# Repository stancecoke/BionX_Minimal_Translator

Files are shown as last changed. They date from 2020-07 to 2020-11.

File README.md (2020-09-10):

# BionX_Minimal_Translator

Run a BionX Motor with a Kunteng LCD-Display  



[Discussion in german forum](https://www.pedelecforum.de/forum/index.php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)  
["Bluepill" STM32F103 Board](https://rover.ebay.com/rover/1/707-53477-19255-0/1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)  
[CAN-Driver-Board](https://rover.ebay.com/rover/1/707-53477-19255-0/1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)  
[Step Down Converter 12V + 5V](https://rover.ebay.com/rover/1/707-53477-19255-0/1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)  
[Kunteng Display](https://rover.ebay.com/rover/1/707-53477-19255-0/1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)

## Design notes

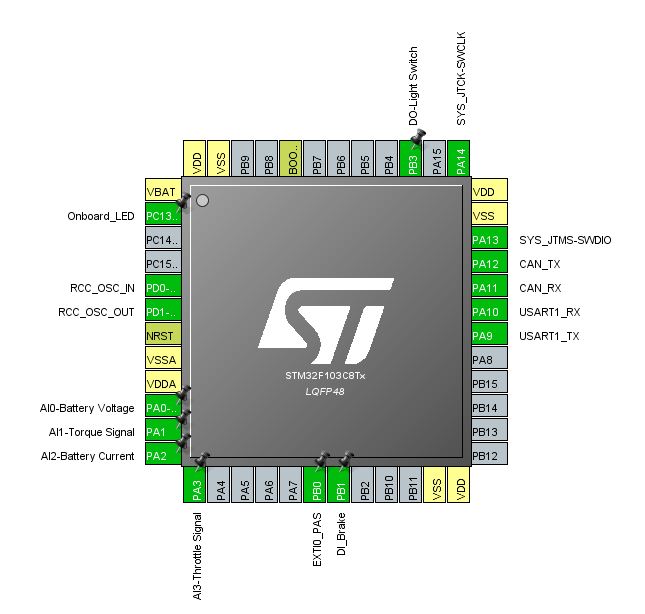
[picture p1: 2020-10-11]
KiCAD/Processor Pinout.JPG

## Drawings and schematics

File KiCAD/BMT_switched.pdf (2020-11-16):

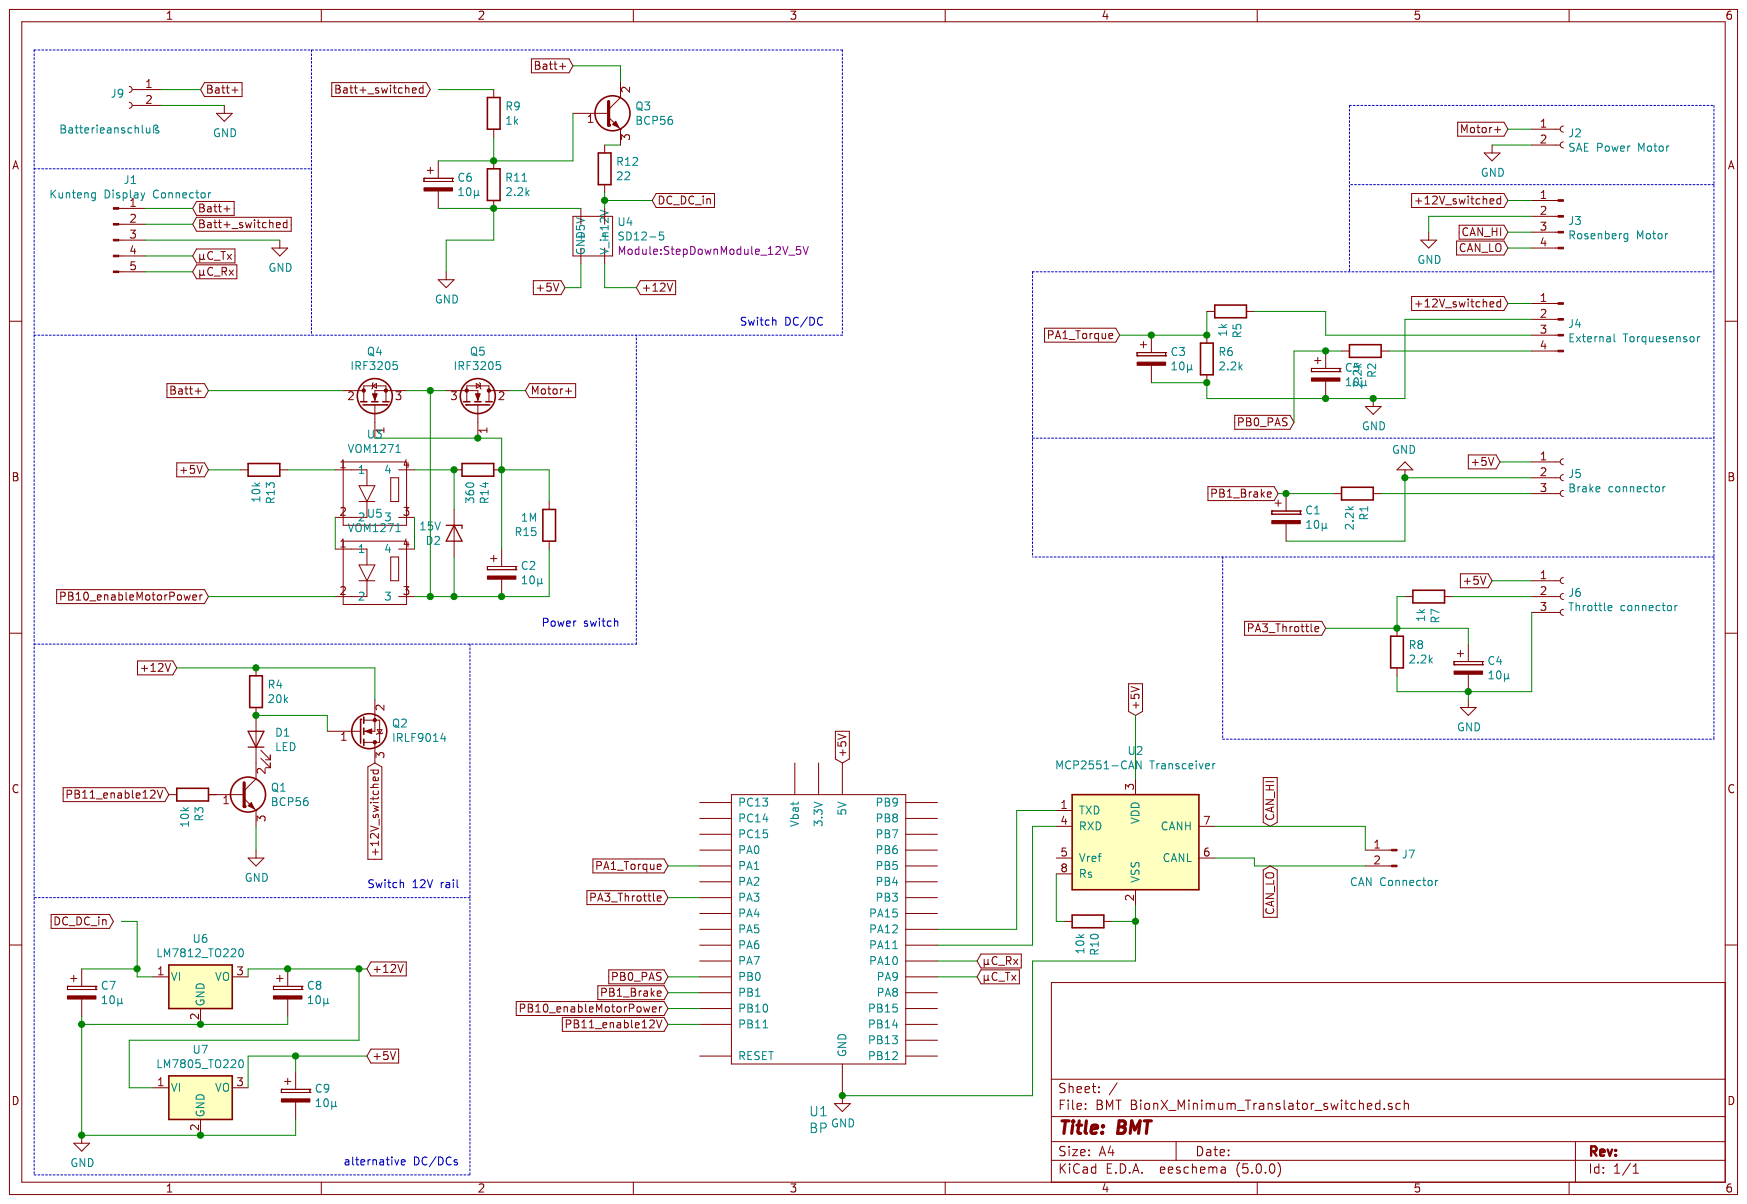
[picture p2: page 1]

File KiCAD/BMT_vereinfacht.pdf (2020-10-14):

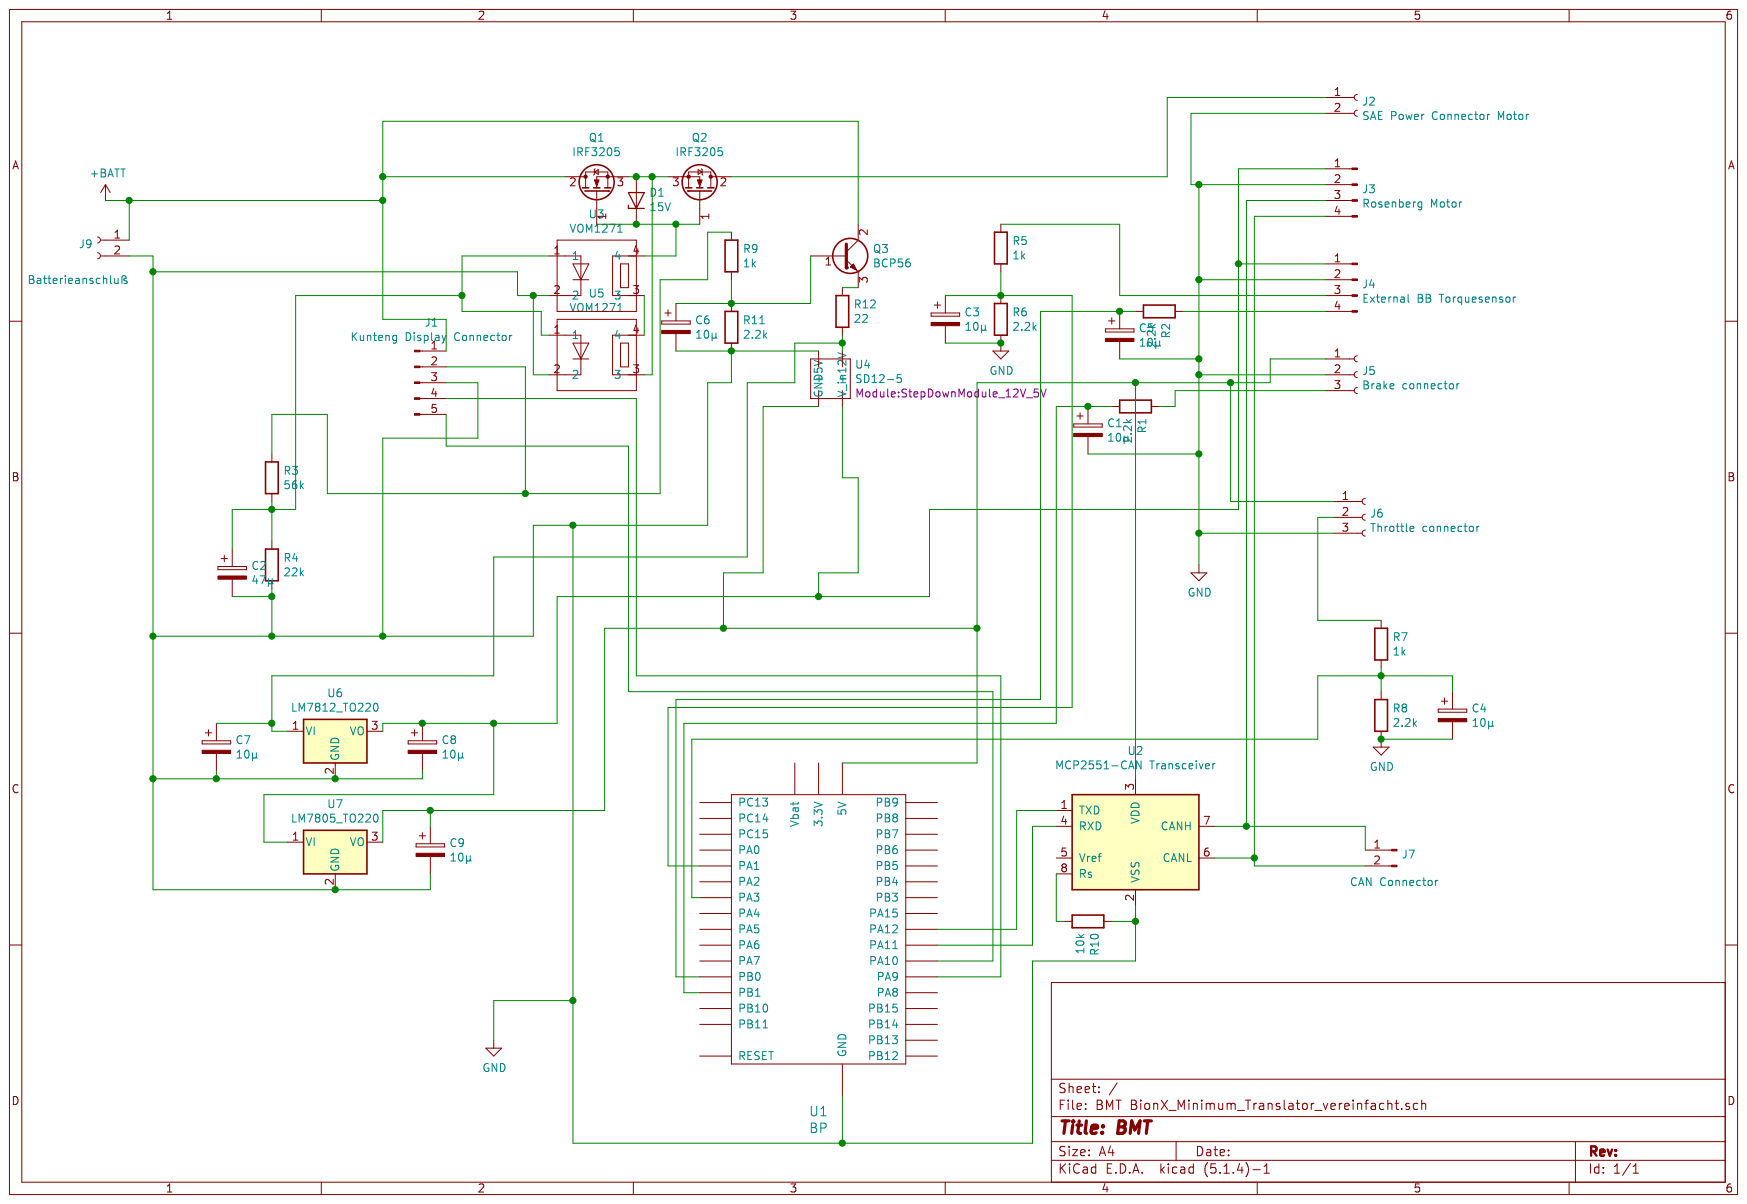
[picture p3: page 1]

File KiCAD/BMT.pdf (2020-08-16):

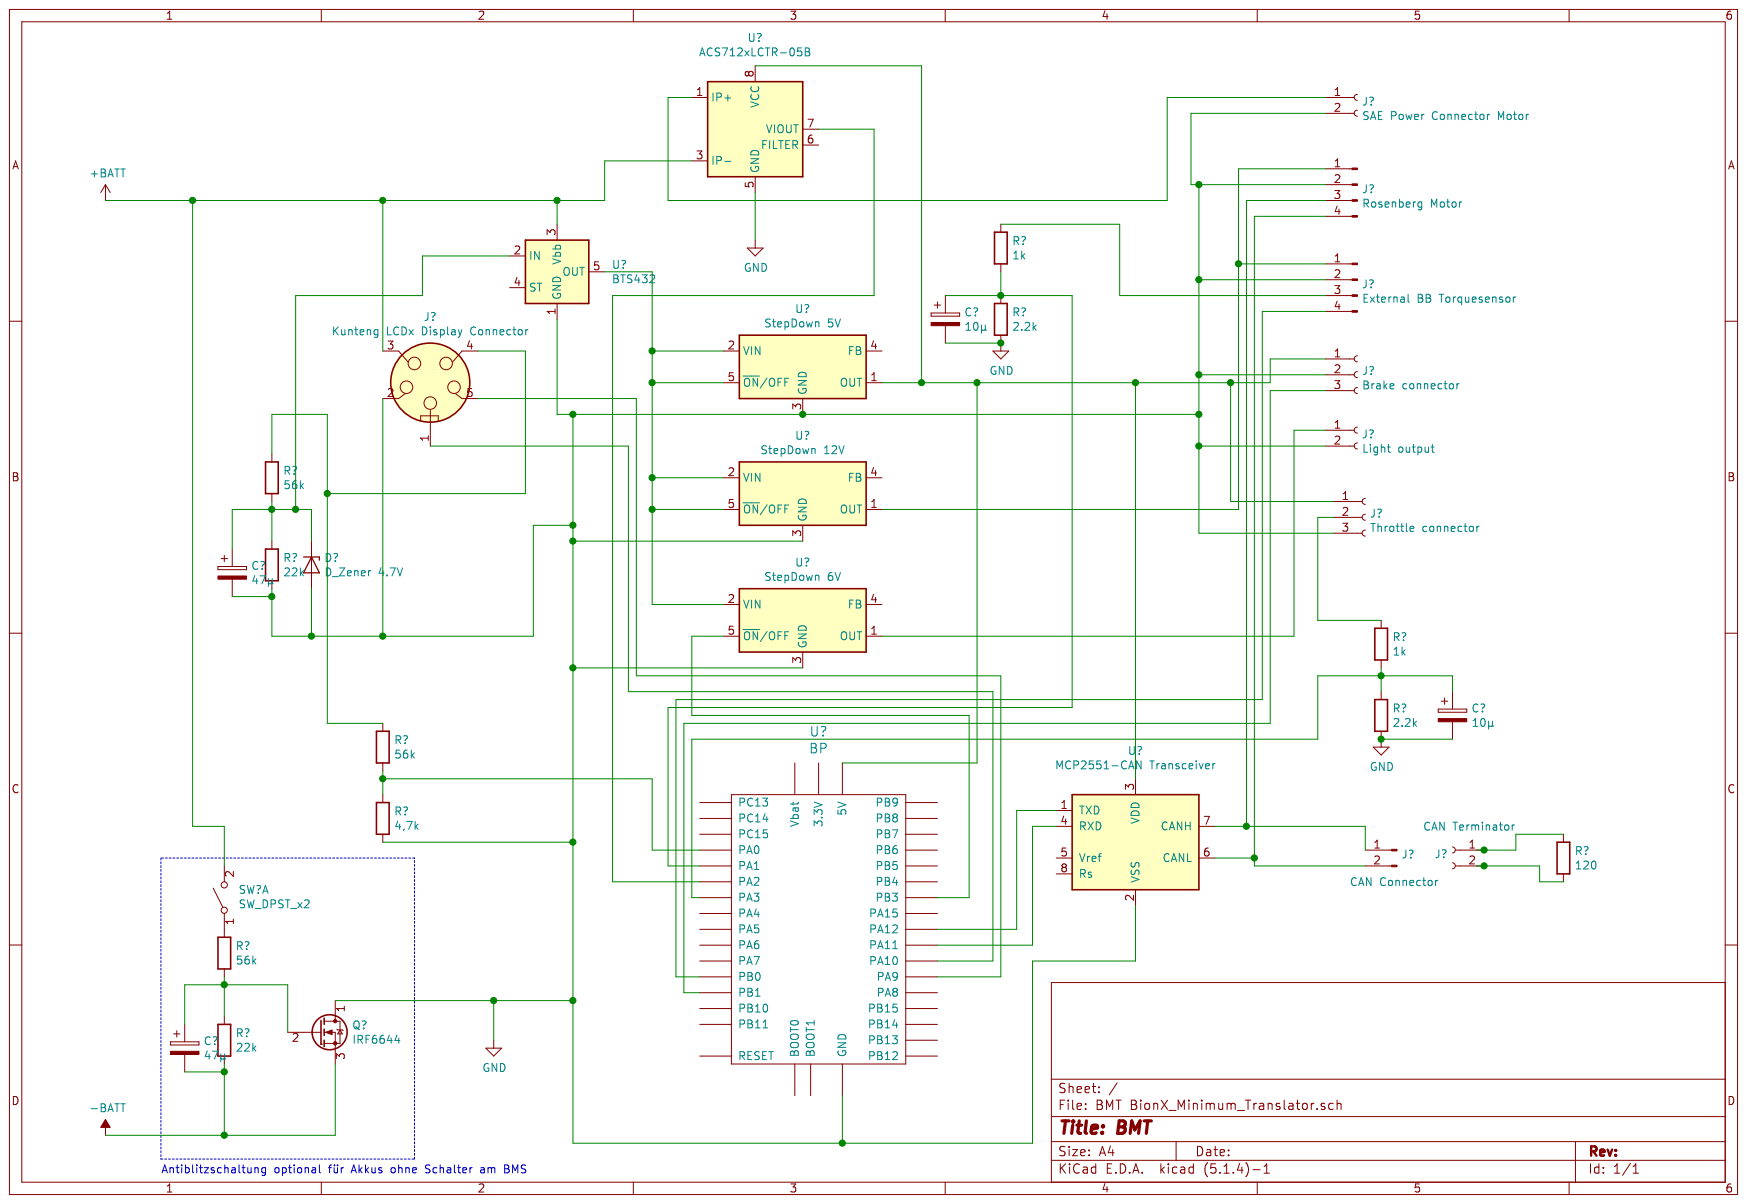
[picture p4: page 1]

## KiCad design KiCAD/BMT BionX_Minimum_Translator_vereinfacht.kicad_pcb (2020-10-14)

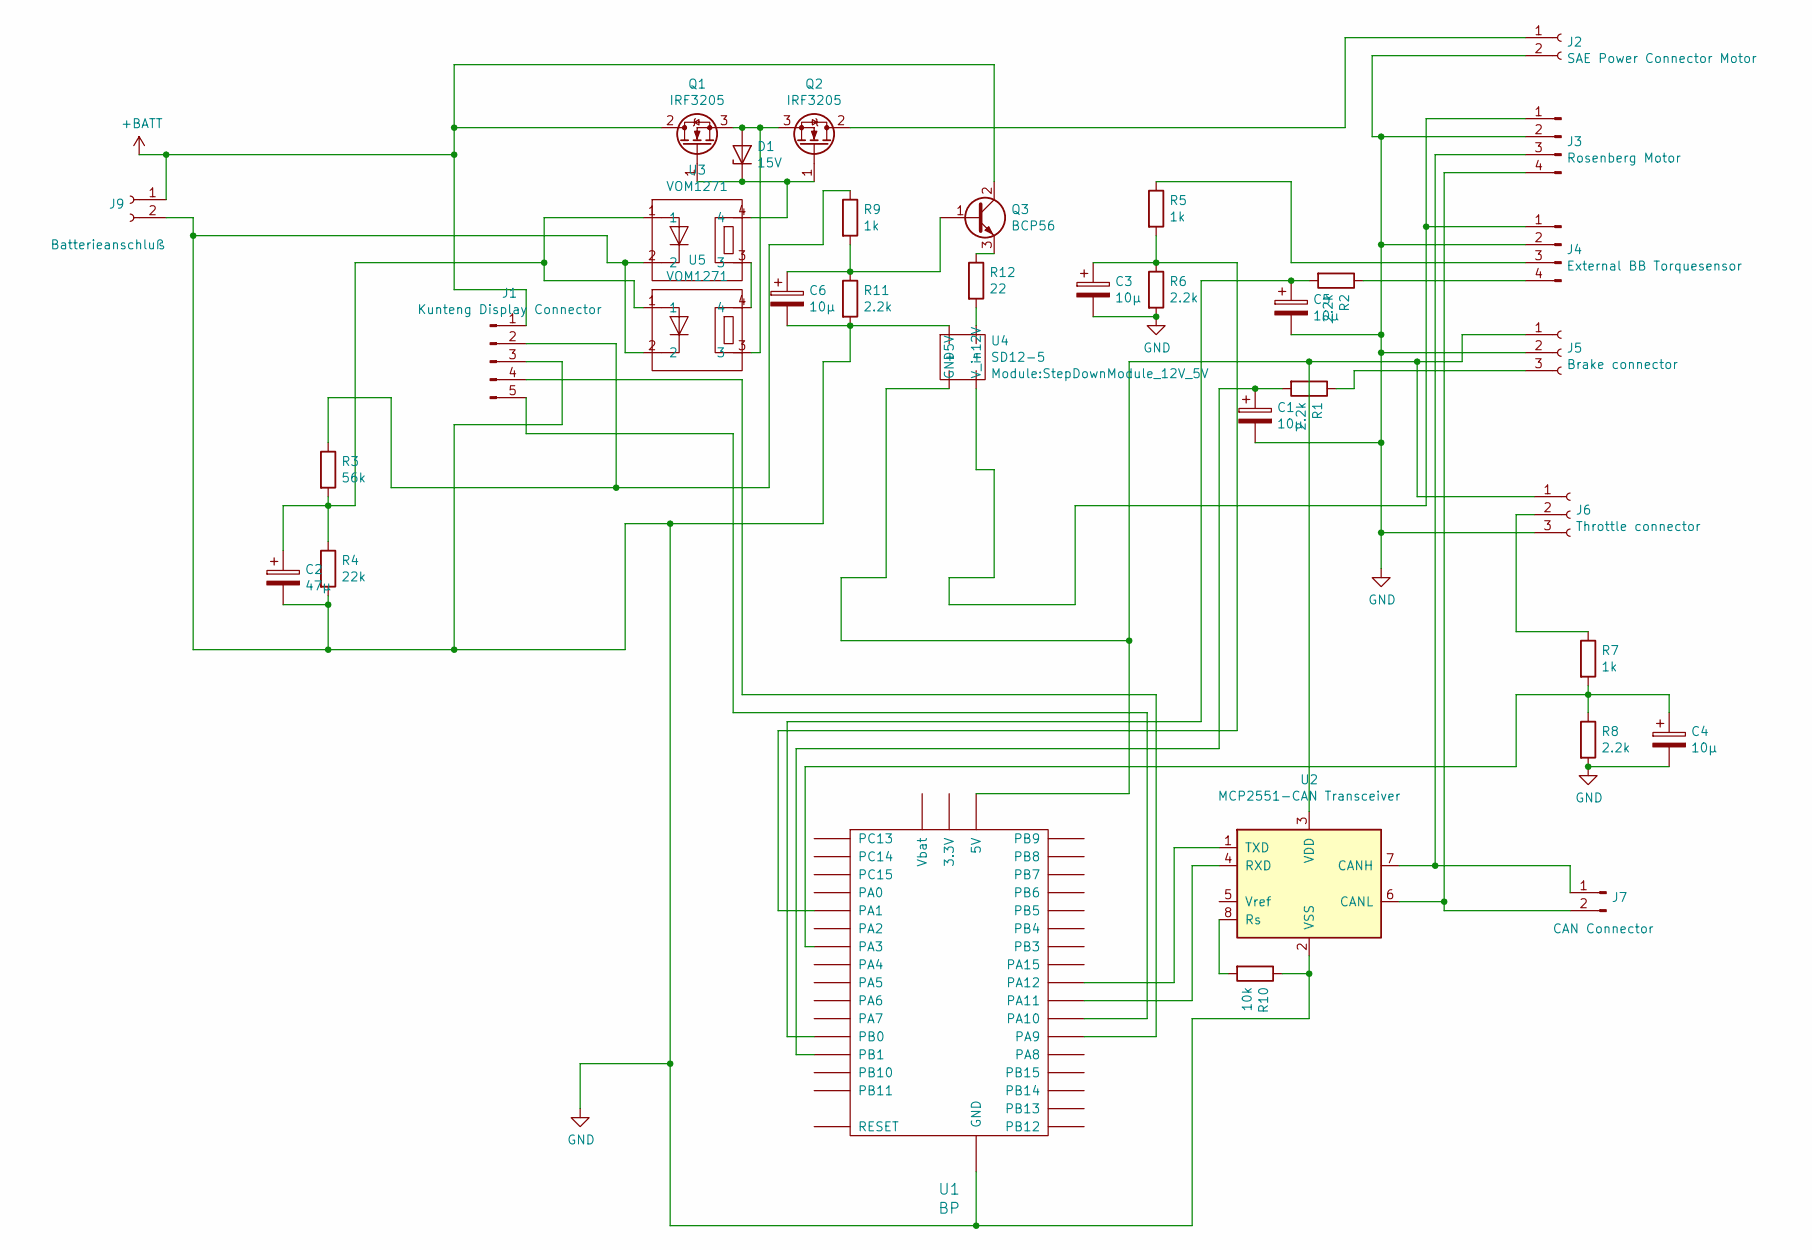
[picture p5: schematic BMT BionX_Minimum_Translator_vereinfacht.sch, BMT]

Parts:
C1, C3, C4, C5, C6: 10µ; CP_Radial_D5.0mm_P2.50mm
C2: 47µ; CP_Radial_D5.0mm_P2.50mm
D1: 15V; D_0805_2012Metric
J1: Kunteng Display Connector; JST_EH_B5B-EH-A_1x05_P2.50mm_Vertical
J2: SAE Power Connector Motor; Wago_734-132_1x02_P3.50mm_Vertical
J3: Rosenberg Motor; JST_EH_B4B-EH-A_1x04_P2.50mm_Vertical
J4: External BB Torquesensor; JST_EH_B4B-EH-A_1x04_P2.50mm_Vertical
J5: Brake connector; JST_EH_B3B-EH-A_1x03_P2.50mm_Vertical
J6: Throttle connector; JST_EH_B3B-EH-A_1x03_P2.50mm_Vertical
J7: CAN Connector; JST_EH_B2B-EH-A_1x02_P2.50mm_Vertical
J9: Batterieanschluß; Wago_734-132_1x02_P3.50mm_Vertical
Q1, Q2: IRF3205; TO-220-3_Vertical
Q3: BCP56; SOT-223
R1, R2, R6, R8, R11: 2.2k; R_0805_2012Metric
R3: 56k; R_0805_2012Metric
R4: 22k; R_0805_2012Metric
R5, R7, R9: 1k; R_0805_2012Metric
R10: 10k; R_0805_2012Metric
R12: 22; R_0805_2012Metric
U1: BP; BluePill
U2: MCP2551-CAN Transceiver; SOIC-8-1EP_3.9x4.9mm_P1.27mm_EP2.29x3mm
U3, U5: VOM1271; SOP-4_3.8x4.1mm_P2.54mm
U4: SD12-5; StepDownModule_12V_5V

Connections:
+BATT: J1.1, J9.1, Q1.2 (D), Q3.2 (C), Q3.4 (C)
GND: C1.2, C2.2, C3.2, C4.2, C5.2, C6.2, J1.3, J2.2, J3.2, J4.2, J5.2, J6.3, J9.2, R4.2, R6.2, R8.2, R10.1, R11.2, U1.GND, U2.2 (VSS), U3.2, U4.GND, U5.2; also elsewhere on the board
unnamed: C1.1, R1.2, U1.PB1
unnamed: C2.1, R3.2, R4.1, U3.1, U5.1
unnamed: C3.1, R5.2, R6.1, U1.PA1
unnamed: C4.1, R7.2, R8.1, U1.PA3
unnamed: C5.1, R2.2, U1.PB0
unnamed: C6.1, Q3.1 (B), R9.2, R11.1
unnamed 8: R12.2, U4.V_in; also elsewhere on the board
unnamed 9: J3.1, J4.1, U4.+12V; also elsewhere on the board
unnamed 10: J5.1, J6.1, U1.5V, U2.3 (VDD), U4.+5V; also elsewhere on the board
unnamed: D1.1 (K), Q1.1 (G), Q2.1 (G), U3.4
unnamed: D1.2 (A), Q1.3 (S), Q2.3 (S), U5.3
unnamed: J1.2, R3.1, R9.1
unnamed: J1.4, U1.PA9
unnamed: J1.5, U1.PA10
unnamed: J2.1, Q2.2 (D)
unnamed: J3.3, J7.1, U2.7 (CANH)
unnamed: J3.4, J7.2, U2.6 (CANL)
unnamed: J4.3, R5.1
unnamed: J4.4, R2.1
unnamed: J5.3, R1.1
unnamed: J6.2, R7.1
unnamed: Q3.3 (E), R12.1
unnamed: R10.2, U2.8 (Rs)
unnamed: U1.PA11, U2.4 (RXD)
unnamed: U1.PA12, U2.1 (TXD)
unnamed: U3.3, U5.4

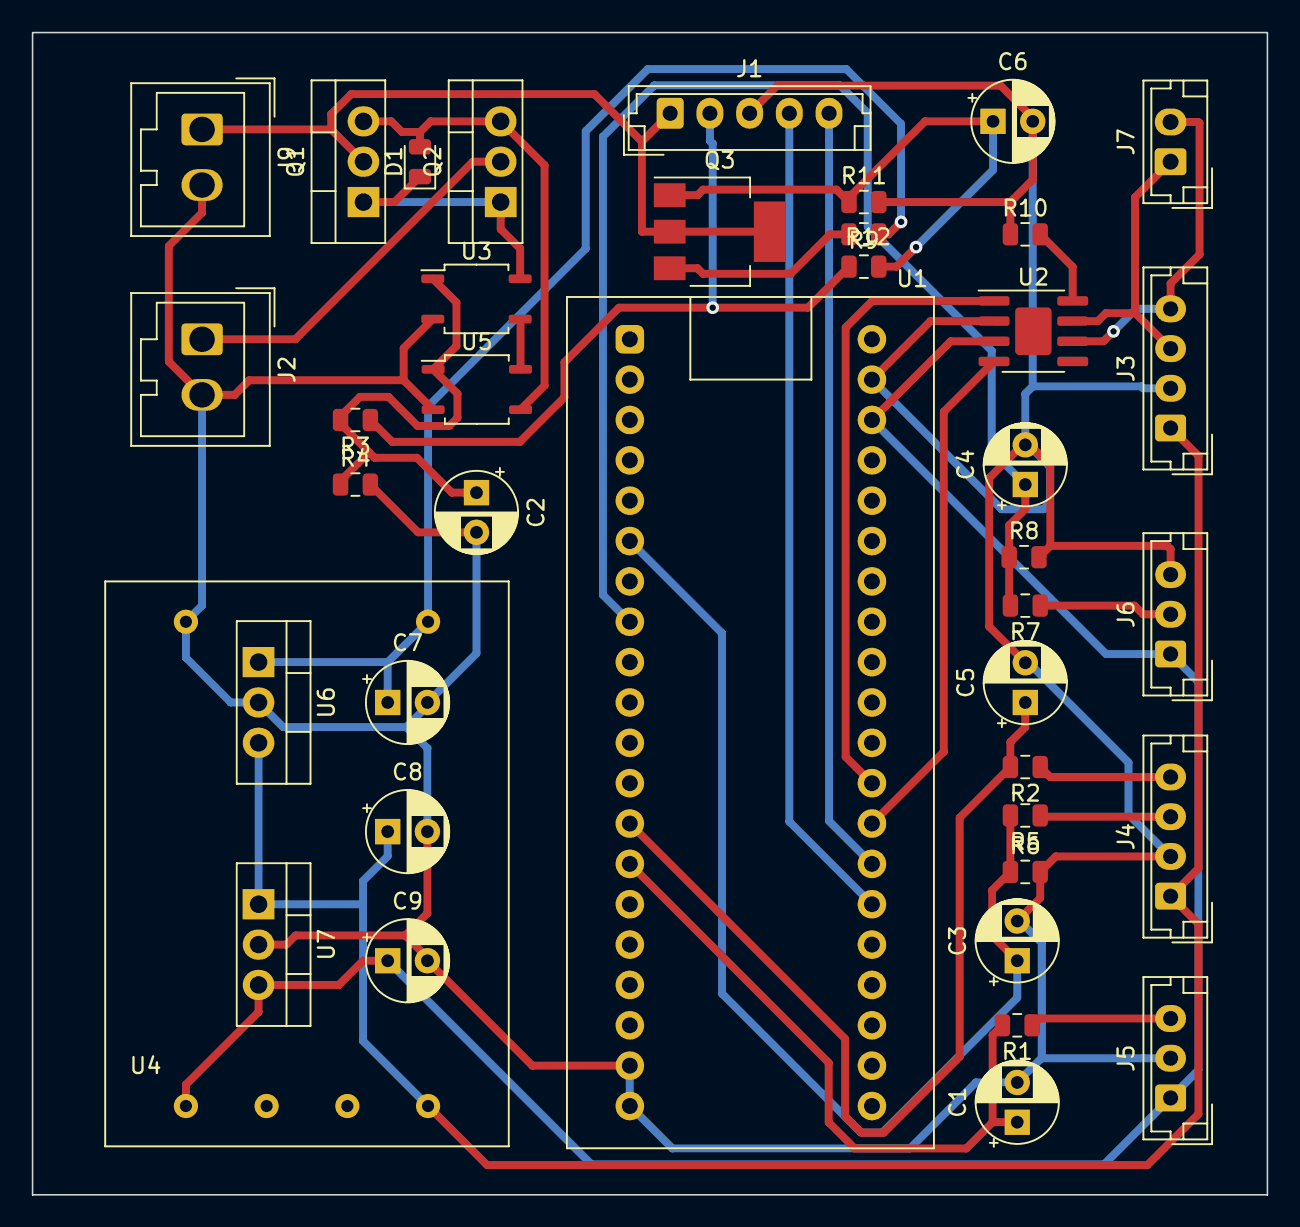
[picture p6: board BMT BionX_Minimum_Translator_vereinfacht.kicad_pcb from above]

Board: 2 copper layers, 77.7 x 73.2 mm, 40 parts (0 on the bottom side), 28 nets.

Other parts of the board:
C7, C8, C9: 10µ; CP_Radial_D5.0mm_P2.50mm
U6: LM7812_TO220; TO-220-3_Vertical
U7: LM7805_TO220; TO-220-3_Vertical

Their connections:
GND: C7.2, C8.2, C9.2, U6.2, U7.2; also elsewhere on the board
unnamed 8: C7.1, U6.1; also elsewhere on the board
unnamed 9: C8.1, U6.3, U7.1; also elsewhere on the board
unnamed 10: C9.1, U7.3; also elsewhere on the board

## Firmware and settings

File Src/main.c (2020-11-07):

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

/* Includes ------------------------------------------------------------------*/
#include "main.h"

/* USER CODE BEGIN Includes */
#include <stdio.h>
#include "config.h"
#include "display_kunteng.h"
#include "CAN-Registers.h"
/* USER CODE END Includes */

ADC_HandleTypeDef hadc1;
DMA_HandleTypeDef hdma_adc1;

CAN_HandleTypeDef hcan;

TIM_HandleTypeDef htim3;

UART_HandleTypeDef huart1;
DMA_HandleTypeDef hdma_usart1_rx;
DMA_HandleTypeDef hdma_usart1_tx;

/* USER CODE BEGIN PV */
char UART_TX_Buffer[100];
char UART_RX_Buffer[100];
uint8_t i=0; //counter for loops
uint8_t j=0; //counter for autozero at startup
uint8_t k=0; //counter for fast CAN_TX
uint8_t l=0; //counter for slow CAN_TX
uint8_t UART_RX_Flag=0;
uint8_t Brake_Flag_Old=0;
uint8_t UART_TX_Flag=1;
uint8_t CAN_RX_Flag=0;
uint8_t CAN_TX_Flag=0;
uint8_t Timer3_Flag=0;
uint8_t ADC_Flag=0;
uint8_t PAS_Flag=0;
char ch_GaugeVoltage_Lo=0;
char ch_GaugeVoltage_Hi=0;
char ch_BatteryVoltage_Lo=0;
char ch_BatteryVoltage_Hi=0;

int8_t i8_Throttle=0; //must be scaled to valid values from -64 ... +64
int16_t i16_Gauge_Torque=0;
int16_t i16_Gauge_Timeout_counter=0;
int16_t i16_Gauge_Voltage=0;
uint16_t ui16_Ext_Torque=0;
uint32_t ui32_Ext_Torque_Cumulated=0;
int16_t i16_PAS_Counter=0;
int16_t i16_PAS_Duration=PAS_TIMEOUT;
int32_t i32_Gauge_Torque_cumulated=0;
int32_t i32_Speed_cumulated=0;
int16_t i16_Current_Target=0;
uint16_t ui16_slow_loop_counter=0;
uint16_t ui16_Gauge_Gain;
volatile uint16_t adcData[4]; //Buffer for ADC1 Input
MotorState_t MS; //struct for motor state


CAN_TxHeaderTypeDef   TxHeader;
CAN_RxHeaderTypeDef   RxHeader;
uint8_t               TxData[8];
uint8_t               RxData[8];
uint32_t              TxMailbox;
/* USER CODE END PV */

void SystemClock_Config(void);
static void MX_GPIO_Init(void);
static void MX_DMA_Init(void);
static void MX_CAN_Init(void);
static void MX_USART1_UART_Init(void);
static void MX_ADC1_Init(void);
static void MX_TIM3_Init(void);


int32_t map (int32_t x, int32_t in_min, int32_t in_max, int32_t out_min, int32_t out_max);
int16_t PI_control (int16_t ist, int16_t soll, int16_t max);
/**
  * @brief  The application entry point.
  * @retval int
  */
int main(void)
{
  /* MCU Configuration--------------------------------------------------------*/

  /* Reset of all peripherals, Initializes the Flash interface and the Systick. */
  HAL_Init();

  /* Configure the system clock */
  SystemClock_Config();

  /* Initialize all configured peripherals */
  MX_GPIO_Init();
  MX_DMA_Init();
  MX_CAN_Init();
  MX_USART1_UART_Init();
  MX_ADC1_Init();
#if (DISPLAY_TYPE == DISPLAY_TYPE_KUNTENG)
  kunteng_init();
#endif
  /* Run the ADC CALIB_GAUGEration */


  {
    /* CALIB_GAUGEration Error */
    Error_Handler();
  }

  MX_TIM3_Init();

  // Start Timer 3

  if(HAL_TIM_Base_Start_IT(&htim3) != HAL_OK)
       {
         /* Counter Enable Error */
         Error_Handler();
       }
  // Start ADC1 with DMA
  HAL_ADC_Start_DMA(&hadc1, (uint32_t*)adcData, 4);

  /* USER CODE BEGIN 2 */

  UART_RX_Buffer[0]=0;


  while(!CAN_RX_Flag){ //So lange Versionsanfrage senden, bis Antwort vom BionX-Controller kommt, dabei blinken.
  	  HAL_Delay(200);
  	  HAL_GPIO_TogglePin(Onboard_LED_GPIO_Port, Onboard_LED_Pin);
		Send_CAN_Request(REG_MOTOR_REV_SW);

		  }
  HAL_Delay(200);

  MS.Gauge_Ext_Torq_Flag = 1; 	//set torque source to external BB-sensor by default. Is overwritten by KT-LCD setting of P3 at runtime.
  MS.Assist_Level = 3;			//set Assistlevel to 3 as default value
  MS.Gauge_Factor = 127;		//default for global gain for torque measurement, set by Kunteng Paramter P1 0 ... 255
  MS.Regen_Factor = 4;			//default regen strenght for brake lever regen
  MS.Throttle_Function = 0; 	//Throttle override for power and regen
  MS.Min_Voltage = 33000;		//minimum Voltage (mV) for 10s pack as default
  MS.Max_Voltage = 41500;		//maximum Voltage (mV) for 10s pack as default
  MS.Filter = 6;				//Filter over 64 readings as default.

  /* USER CODE END 2 */

  /* Infinite loop */
  /* USER CODE BEGIN WHILE */
  while (1)
  {



	  if(UART_RX_Flag){
		  UART_RX_Flag=0;

#if (DISPLAY_TYPE == DISPLAY_TYPE_DEBUG)
		  if(UART_TX_Flag){
			 UART_TX_Flag=0;


		  	sprintf(UART_TX_Buffer, "Empfangenes UART Byte %d, %d, %d, %d\r\n",UART_RX_Buffer[0],UART_RX_Buffer[1], UART_RX_Buffer[2], UART_RX_Buffer[3]);

		  	  	  i=0;
		  	  	  while (UART_TX_Buffer[i] != '\0')
		  	  	  {i++;}


		  	  	HAL_UART_Transmit_DMA(&huart1, (uint8_t *)&UART_TX_Buffer, i);

		  }

		  	  if(CAN_TX_Flag && UART_RX_Buffer[0]==1){
		  		CAN_TX_Flag=0;
		  		Send_CAN_Command(UART_RX_Buffer[1],((uint16_t)UART_RX_Buffer[2]<<8)+UART_RX_Buffer[3]); //send command with UART-Input
		  	  }


#endif
#if (DISPLAY_TYPE == DISPLAY_TYPE_KUNTENG)
		  	check_message(&MS);

#endif
	  } //end uart rx flag

	  //Timer 3 running with 1kHz ISR frequency
	  if(Timer3_Flag){

		  Timer3_Flag=0;
		  ui16_slow_loop_counter++;
		  if (i16_PAS_Counter<PAS_TIMEOUT)i16_PAS_Counter++;

		  MS.Voltage=ch_BatteryVoltage_Hi<<8|ch_BatteryVoltage_Hi; //Battery Voltage in mV
		  i16_Gauge_Voltage=ch_GaugeVoltage_Hi<<8|ch_GaugeVoltage_Lo;

		  //Bremseingang abfragen
		  MS.Brake=HAL_GPIO_ReadPin(Brake_GPIO_Port, Brake_Pin);
		  // hier ggf. noch entprellen?
		  if(MS.Brake==0 && Brake_Flag_Old==1){
			  PI_control (MS.Voltage, MS.Max_Voltage, 0); //reset integral part of PI control, if brake lever is released
			  if(MS.Assist_Level==0){ //Toggle
				  if(MS.Perma_Regen)MS.Perma_Regen=0;
				  else MS.Perma_Regen=1;
			  }
		  }
		  Brake_Flag_Old=MS.Brake;
		  //read in throttle signal
		  i8_Throttle=map(adcData[3],THROTTLE_MIN,THROTTLE_MAX, 0, 63); //map throttle ADC-value to valid LEVEL range

		  //process PAS signal
		  if (PAS_Flag){
			  HAL_GPIO_TogglePin(Onboard_LED_GPIO_Port, Onboard_LED_Pin);
			  PAS_Flag=0;
			  i16_PAS_Duration=i16_PAS_Counter;
			  i16_PAS_Counter=0;
			  ui16_Ext_Torque=map(adcData[1],EXT_TORQUE_MIN, EXT_TORQUE_MAX, 0, 1024); //map throttle ADC-value to valid LEVEL range
			  ui32_Ext_Torque_Cumulated-=ui32_Ext_Torque_Cumulated>>MS.Filter;
			  ui32_Ext_Torque_Cumulated+=ui16_Ext_Torque;

		  }

		  if (ui16_slow_loop_counter>5){

			  ui16_slow_loop_counter=0;

			  //Brake acitve, do constant regen
			  if(!MS.Brake){
				  i16_Current_Target = (-CALIB_REGEN*(MS.Regen_Factor+1))>>3;		//regen via brake lever
				  if(!MS.Throttle_Function)i8_Throttle=-i8_Throttle;
			  }
			  //Perma Regen active, do regen according to assist level
			  else if(MS.Perma_Regen){
				  i16_Current_Target = (-CALIB_REGEN*MS.Assist_Level)/5;		//permanent regen switched by tip on brake lever in level 0
				  if(!MS.Throttle_Function)i8_Throttle=-i8_Throttle;
			  }
			  // if internal Gauge is active (selected by P3), calculate current target from Gauge Value,
			  else if(MS.Gauge_Ext_Torq_Flag){
				  i16_Current_Target = (CALIB_GAUGE*(i32_Gauge_Torque_cumulated>>MS.Filter)*MS.Assist_Level*MS.Gauge_Factor)>>7; //normal ride mode
			  	  if(!i16_Gauge_Torque)i16_Gauge_Timeout_counter++;  	//count up readings with gauge value == 0
			  	  else i16_Gauge_Timeout_counter = 0;					//reset timeout counter, when gauge value != 0
			  	  if (i16_Gauge_Timeout_counter>PAS_TIMEOUT-1){			//if gauge value has timed out, slowly decrease Torque_cumulated.
			  		  i16_Gauge_Timeout_counter=PAS_TIMEOUT;
			  		  if(i32_Gauge_Torque_cumulated>0)i32_Gauge_Torque_cumulated--;
			  	  }
			  }
			  // if external torque sensor is active
			  else {
				  i16_Current_Target = (((ui32_Ext_Torque_Cumulated>>MS.Filter)*MS.Assist_Level*MS.Gauge_Factor)>>CALIB_EXT_TORQUE)/(i16_PAS_Duration*(MS.Speed+1));
				  if(i16_PAS_Counter>PAS_TIMEOUT-1){
					  i16_Current_Target=0; //Switch off power, if pedals are not turning
					  if(ui32_Ext_Torque_Cumulated>0)ui32_Ext_Torque_Cumulated--;
					  if(i16_PAS_Duration<PAS_TIMEOUT)i16_PAS_Duration++;

				  }
			  }

			  // limit Current_Target to valid range for LEVEL
			  if(i16_Current_Target>63)i16_Current_Target=63;
			  if(i16_Current_Target<-63)i16_Current_Target=-63;

			  if(!MS.Throttle_Function){
				  // Throttle override for regen and assist

				  if(MS.Gauge_Ext_Torq_Flag){
					  if(i16_Current_Target>=0 && i8_Throttle>0 && i8_Throttle>i16_Current_Target && (MS.Speed<7 || i16_Gauge_Timeout_counter<PAS_TIMEOUT-1 ))i16_Current_Target=i8_Throttle;
				  }
				  else {
					  if(i16_Current_Target>=0 && i8_Throttle>0 && i8_Throttle>i16_Current_Target && (MS.Speed<7 || i16_PAS_Counter<PAS_TIMEOUT-1 ))i16_Current_Target=i8_Throttle;
				  }
				  if(i16_Current_Target<=0 && i8_Throttle<0 && i8_Throttle<i16_Current_Target)i16_Current_Target=i8_Throttle;
			  }
			  else {//linear regen with throttle
				  if(i8_Throttle>2)i16_Current_Target = -i8_Throttle;
			  }

		//	  if (i16_Current_Target<0) i16_Current_Target= -map(MS.Voltage,MS.Max_Voltage-2000,MS.Max_Voltage,-i16_Current_Target,0);
			  if (i16_Current_Target<0) {
				  i16_Current_Target = PI_control (MS.Voltage, MS.Max_Voltage, i16_Current_Target);
			  }
			 /* if (ADC_Flag){
				  ADC_Flag=0;
				  sprintf(UART_TX_Buffer, "ADC Values %d, %d, %d\r\n",adcData[0], adcData[1], adcData[2]);

				  		  	  	  i=0;
				  		  	  	  while (UART_TX_Buffer[i] != '\0')
				  		  	  	  {i++;}

				  		  	  	HAL_UART_IRQHandler(&huart1);
				  		  	  	HAL_UART_Transmit_DMA(&huart1, (uint8_t *)&UART_TX_Buffer, i);
				  		  	  	HAL_Delay(200);

			  }*/

				 // Send next CAN_TX if last CAN transmit is finished
			  if(CAN_TX_Flag){

				  CAN_TX_Flag=0;

				  switch (k) {

				  case 0:
#if (DISPLAY_TYPE == DISPLAY_TYPE_DEBUG)
					  if(!UART_RX_Buffer[0]){

						  Send_CAN_Request(REG_MOTOR_TORQUE_GAUGE_VALUE);

					  }
					  else{

						  Send_CAN_Request(UART_RX_Buffer[1]);
					  }
#endif
#if (DISPLAY_TYPE == DISPLAY_TYPE_KUNTENG)

						  Send_CAN_Request(REG_MOTOR_TORQUE_GAUGE_VALUE);

#endif
					  k++;
				  break;

				  case 1:
				  // send current target to BionX controller, perhaps 2 times, perhaps wait for CAN TX ready.
#if (DISPLAY_TYPE == DISPLAY_TYPE_DEBUG)
					  if(!UART_RX_Buffer[0]){
						if(MS.Voltage>MS.Min_Voltage) Send_CAN_Command(REG_MOTOR_ASSIST_LEVEL,i16_Current_Target); //send current target only when battery voltage is high enough
						else CAN_TX_Flag = 1;
					  }
					  else{
						  Send_CAN_Request(REG_MOTOR_STATUS_TEMPERATURE);
					  }
#endif
#if (DISPLAY_TYPE == DISPLAY_TYPE_KUNTENG)

					  if(MS.Voltage>MS.Min_Voltage) Send_CAN_Command(REG_MOTOR_ASSIST_LEVEL,i16_Current_Target); //send current target only when battery voltage is high enough
					  else CAN_TX_Flag = 1;

#endif

					  k++;
				  break;



//slow CAN_TX
				  case 2:
					  switch (l) {

					  	  case 0:
					  		  Send_CAN_Request(REG_MOTOR_STATUS_POWER_METER);
							  l++;
						  break;

					  	  case 1:
					  		Send_CAN_Request(REG_MOTOR_STATUS_TEMPERATURE);
							  l++;
						  break;

						  case 2:
							  Send_CAN_Request(REG_MOTOR_STATUS_SPEED);
							  l++;
						  break;

						  case 3:
							  Send_CAN_Request(REG_MOTOR_STATUS_POWER_VOLTAGE_HI);
							  l++;
						  break;

						  case 4:
							  Send_CAN_Request(REG_MOTOR_STATUS_POWER_VOLTAGE_LO);
							  l++;
						  break;

						  case 5:
							  Send_CAN_Request(REG_MOTOR_TORQUE_GAUGE_GAIN);
							  l=0;
						  break;
/*
						  case 5:
							  Send_CAN_Request(REG_MOTOR_TORQUE_GAUGE_VOLTAGE_LO);
							  l++;
						  break;

						  case 6:
							  Send_CAN_Request(REG_MOTOR_TORQUE_GAUGE_VOLTAGE_HI);
							  l++;
						  break;
*/


					  }//end switch of slow CAN_TX

					  k=0;
				  break;

				  }//end switch of fast CAN_TX
			  }//end TX_Flag

		  }//end slow loop
	  }// end timer 1 kHz loop



	  if(CAN_RX_Flag){

		  CAN_RX_Flag=0;



		  switch (RxData[1]) {

		  case REG_MOTOR_TORQUE_GAUGE_VALUE:
			  i16_Gauge_Torque=RxData[3];
			  i32_Gauge_Torque_cumulated -= (i32_Gauge_Torque_cumulated>>MS.Filter); // FILTER = 6 für 1s Zeitkonstante
			  i32_Gauge_Torque_cumulated += i16_Gauge_Torque;

			  break;

		  case REG_MOTOR_STATUS_SPEED:

			  i32_Speed_cumulated -= i32_Speed_cumulated>>3;
			  i32_Speed_cumulated += RxData[3];
			  MS.Speed = i32_Speed_cumulated>>3;


			  break;

		  case REG_MOTOR_STATUS_POWER_METER:

			  MS.Power=RxData[3];


			  break;

		  case REG_MOTOR_TORQUE_GAUGE_VOLTAGE_HI:

			  ch_GaugeVoltage_Hi=RxData[3];


			  break;

		  case REG_MOTOR_TORQUE_GAUGE_VOLTAGE_LO:

			  ch_GaugeVoltage_Lo=RxData[3];


			  break;

		  case REG_MOTOR_STATUS_TEMPERATURE:

			  MS.MotorTemperature=RxData[3];

			  break;

		  case REG_MOTOR_STATUS_POWER_VOLTAGE_HI:

			  ch_BatteryVoltage_Hi=RxData[3];

			  break;

		  case REG_MOTOR_STATUS_POWER_VOLTAGE_LO:

			  ch_BatteryVoltage_Lo=RxData[3];

			  break;

		  case REG_MOTOR_TORQUE_GAUGE_GAIN:

			  ui16_Gauge_Gain=RxData[3];

			  break;



		  }

#if (DISPLAY_TYPE == DISPLAY_TYPE_DEBUG)
		  //print out received CAN message
		  if(UART_TX_Flag){



		  if(!UART_RX_Buffer[0]){

			  sprintf(UART_TX_Buffer, "%d, %ld, %d, %d, %ld, %d, %d, %d, %d, %d, %d \r\n", MS.MotorTemperature, i32_Gauge_Torque_cumulated, MS.Power, MS.Speed, MS.Voltage, i16_PAS_Duration, i16_Current_Target, i16_Gauge_Torque, ui16_Gauge_Gain, adcData[2], adcData[3]);
			  i=0;
			  while (UART_TX_Buffer[i] != '\0')
			  {i++;}

			  UART_TX_Flag=0;
			  HAL_UART_Transmit_DMA(&huart1, (uint8_t *)&UART_TX_Buffer, i);
		  	  }
		  else {

			  sprintf(UART_TX_Buffer, "%d, %d, %d, %d, %d, %d, %d\r\n", (int16_t) RxHeader.StdId, (int16_t) RxHeader.IDE, (int16_t) RxHeader.DLC, RxData[0],RxData[1],RxData[2],RxData[3]);

			  i=0;
			  while (UART_TX_Buffer[i] != '\0')
			  {i++;}

			  UART_TX_Flag=0;
			  HAL_UART_Transmit_DMA(&huart1, (uint8_t *)&UART_TX_Buffer, i);
		  }


			  }
#endif
		  }//End CAN Rx


	  }


    /* USER CODE END WHILE */



    /* USER CODE BEGIN 3 */
  } //end while loop
  /* USER CODE END 3 */


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
/* USER CODE BEGIN 4 */
void HAL_UART_TxCpltCallback(UART_HandleTypeDef *huart)
{

	UART_TX_Flag=1;
	//HAL_UART_IRQHandler(&huart1);// reset huart1

}

void HAL_UART_RxCpltCallback(UART_HandleTypeDef *huart)
{
	UART_RX_Flag=1;


}


void HAL_CAN_RxFifo0MsgPendingCallback(CAN_HandleTypeDef *CanHandle)
{
  /* Get RX message */
	//HAL_GPIO_TogglePin(Onboard_LED_GPIO_Port, Onboard_LED_Pin);
  if (HAL_CAN_GetRxMessage(CanHandle, CAN_RX_FIFO0, &RxHeader, RxData) != HAL_OK)
  {
    /* Reception Error */
    Error_Handler();
  }

  CAN_RX_Flag=1;

}

void HAL_CAN_TxMailbox0CompleteCallback(CAN_HandleTypeDef *CanHandle)
{


	CAN_TX_Flag=1;

}

void HAL_TIM_PeriodElapsedCallback(TIM_HandleTypeDef *htim)
{
	if (htim == &htim3) {
		Timer3_Flag=1;


	}
}

// regular ADC callback
void HAL_ADC_ConvCpltCallback(ADC_HandleTypeDef* hadc)
{
	ADC_Flag=1;

}

void HAL_GPIO_EXTI_Callback(uint16_t GPIO_Pin)
{
	PAS_Flag=1;

}

void Send_CAN_Request(uint8_t command){

	TxHeader.StdId=ID_MOTOR;
	TxHeader.DLC=2;
	TxData[0] = 0;
	TxData[1] = command;

	//HAL_GPIO_TogglePin(Onboard_LED_GPIO_Port, Onboard_LED_Pin);
	if (HAL_CAN_AddTxMessage(&hcan, &TxHeader, TxData, &TxMailbox) != HAL_OK)
	   	{
    	  Error_Handler();
    	}


}



void Send_CAN_Command(uint8_t function, uint16_t value){
	TxHeader.StdId=ID_MOTOR;
	TxHeader.DLC=4;
	TxData[0] = 0;
	TxData[1] = function;
	TxData[2] = (value>>8) & 0xff;
	TxData[3] = value & 0xff;

	// Start the Transmission process, zwei mal senden wie im Beispiel https://github.com/jliegner/bionxdrive
	if (HAL_CAN_AddTxMessage(&hcan, &TxHeader, TxData, &TxMailbox) != HAL_OK)
	  {
	   // Transmission request Error
	   Error_Handler();
	  }

}

int32_t map (int32_t x, int32_t in_min, int32_t in_max, int32_t out_min, int32_t out_max)
{
  // if input is smaller/bigger than expected return the min/max out ranges value
  if (x < in_min)
    return out_min;
  else if (x > in_max)
    return out_max;

  // map the input to the output range.
  // round up if mapping bigger ranges to smaller ranges
  else  if ((in_max - in_min) > (out_max - out_min))
    return (x - in_min) * (out_max - out_min + 1) / (in_max - in_min + 1) + out_min;
  // round down if mapping smaller ranges to bigger ranges
  else
    return (x - in_min) * (out_max - out_min) / (in_max - in_min) + out_min;
}

//PI control for smooth cut off of regen power with full battery
int16_t PI_control (int16_t ist, int16_t soll, int16_t max)
{

	float flt_p; //proportional part
	static float flt_i = 0; 			//integral part
	if(max == 0)flt_i=0; 				//reset integral part, if brake lever is released
	static float flt_pplusi = 0; 		// sum of proportional and integral part
	flt_p = (soll - ist)*P_FACTOR;
	flt_i += ((float)(soll - ist))*I_FACTOR;
	if(flt_i>63) flt_i=63;
	if(flt_i<-10) flt_i=-10;
	flt_pplusi = flt_p + flt_i;
	if(flt_pplusi >- max) flt_pplusi=-max;
	if(flt_pplusi < 0 ) flt_pplusi=0;

	return (-flt_pplusi);
}


/* USER CODE END 4 */
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


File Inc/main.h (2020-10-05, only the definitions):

#define Onboard_LED_Pin GPIO_PIN_13
#define Onboard_LED_GPIO_Port GPIOC
#define Throttle_Pin GPIO_PIN_3
#define Throttle_GPIO_Port GPIOA
#define Torque_Pin GPIO_PIN_1
#define Torque_GPIO_Port GPIOA
#define BatteryVoltage_Pin GPIO_PIN_0
#define BatteryVoltage_GPIO_Port GPIOA
#define BatteryCurrent_Pin GPIO_PIN_2
#define BatteryCurrent_GPIO_Port GPIOA
#define Light_Pin GPIO_PIN_3
#define Light_GPIO_Port GPIOB
#define Brake_Pin GPIO_PIN_1
#define Brake_GPIO_Port GPIOB
#define PAS_Pin GPIO_PIN_0 //for Exti0 interrupt. Px0 lines have to be considered, https://stm32f4-discovery.net/2014/08/stm32f4-external-interrupts-tutorial/
#define PAS_GPIO_Port GPIOB
#define CAL_BAT_V 1
#define PULSES_PER_REVOLUTION 1

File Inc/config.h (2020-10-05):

/*
 * config.h
 *
 *  Created on: 30.07.2020
 *      Author: stancecoke
 */

#ifndef CONFIG_H_
#define CONFIG_H_

#define CALIB_GAUGE 1	 		// calibration factor for DMS-Torque, better value not known :-)
#define CALIB_EXT_TORQUE 3	// calibration factor for DMS-Torque, better value not known :-)
#define CALIB_REGEN 64 			//calibration factor for regen


#define THROTTLE_MIN 640
#define THROTTLE_MAX 3450

#define EXT_TORQUE_MIN 1190
#define EXT_TORQUE_MAX 2400

#define PAS_TIMEOUT 300

//predefine Display Types
#define DISPLAY_TYPE_KUNTENG (1<<1)							// For use with Kunteng LCD Displays
#define DISPLAY_TYPE_DEBUG (1<<0)							// For ASCII-Output in Debug mode);

#define P_FACTOR 0.001
#define I_FACTOR 0.0001

//Select display
#define DISPLAY_TYPE DISPLAY_TYPE_KUNTENG
#endif /* CONFIG_H_ */

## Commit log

2020-06-16 libraries for Kunteng-Displays added.
    [BionX_Minimum_Translator Debug.cfg]
2020-06-25 WIP for switch to latest HAL-version
2020-06-25 Switch to latest HAL-Driver
    [BionX_Minimum_Translator Debug.cfg]
2020-06-26 BionX command with input from UART
    [launchConfiguration.cfg]
2020-06-27 Blink on PC13 for indication
    [BionX_Minimum_Translator Debug.cfg]
2020-07-01 New approach with most recent HAL library
    [BionX_Minimum_Translator Run.cfg, launchConfiguration.cfg]
2020-07-01 Disable Ring Buffer for UART_TX, Reset UART before each send command
    [main.c]
2020-07-04 bugfix in CAN-handler naming
    [main.c]
2020-07-05 WIP CAN RX interrupt still not working
    [main.c]
2020-07-06 CAN TX Interrupt working now
2020-07-13 Timing with timer3@1kHz, ADC with DMA
2020-07-25 hi-Byte and lo-Byte from UART
2020-07-26 UART first byte 0 TorqueOut, 1 Command, 2 Request
2020-07-30 calculate current target and send it to motor controller
2020-07-30 Workaround for gauge_voltage resets
    [config.h, main.c]
2020-07-31 KiCAD files added
    [BMT BionX_Minimum_Translator.kicad_pcb, BMT BionX_Minimum_Translator.sch, _saved_BMT BionX_Minimum_Translator.sch]
2020-08-01 KiCAD: Switch on hi-side with BTS432
2020-08-01 bugfix in schematic
    [BMT BionX_Minimum_Translator.sch]
2020-08-01 again bugfix in schematic
    [BMT BionX_Minimum_Translator.sch]
2020-08-01 Zener diode at HiSide-Switch input added
    [BMT BionX_Minimum_Translator.sch]
2020-08-02 bugfix in pinout of BTS432
    [BMT BionX_Minimum_Translator.sch]
2020-08-02 WIP timer3 interrupt processing not reliable
2020-08-03 Can termination resistor added
    [BMT BionX_Minimum_Translator.sch]
2020-08-03 Bugfix for paranthesis in #ifs
    [main.c]
2020-08-03 read Speed and Power via CAN from the motor
2020-08-04 toggle led only if CAN TX ready
2020-08-04 update KiCAD schematic
    [BMT BionX_Minimum_Translator.sch]
2020-08-04 send only requested value und debug mode
2020-08-05 riders torque read from 0x21
2020-08-05 Throttle added with override function for regen and power
2020-08-06 support for external torque sensor, activated by parameter P3
2020-08-06 voltage devider 5V -> 3.3v in schematic, adc-values print in debugmode
    [BMT BionX_Minimum_Translator.sch]
2020-08-08 bugfix in adc init
    [main.c]
2020-08-08 capacitors on analog inputs added to schematic
    [BMT BionX_Minimum_Translator.sch]
2020-08-09 Power and Speed added to printout
2020-08-13 Dispaly Max Speed and Wheelsize settings sent to Motor if changed
2020-08-13 scaling of speed display corrected
    [CAN-Registers.h, config.h, display_kunteng.c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]
2020-08-13 setting of serial battery cells with P2
2020-08-15 bugfix in debug mode
    [config.h, main.c]
2020-08-16 Update of schematic with untested "Antiblitz"
    [BMT BionX_Minimum_Translator.sch]
2020-08-29 WIP debugging external torquesensor function
2020-08-29 Success: assist with external torquesensor is working now.
2020-08-31 Throttle function per P4, Battery max current per C2
2020-09-13 gauge voltage added to debug output
2020-09-15 default value for Throttle function added
2020-09-16 send current target only if battery voltage is high enough
2020-09-26 Changed to PI control for keeping max voltage limit at regen.
2020-10-05 Filter and Gauge Gain implemented as C4 and C5 parameter
2020-10-05 timeout of gauge value added for legalizing of throttle
2020-10-05 bugfix in gauge timeout
    [main.c]
2020-10-09 simplified schematic added
    [BMT BionX_Minimum_Translator_vereinfacht.sch]
2020-10-09 PDF of schematic added
    [BMT BionX_Minimum_Translator_vereinfacht.sch]
2020-10-11 Processor pinout added
    [BMT BionX_Minimum_Translator_vereinfacht.kicad_pcb, BMT BionX_Minimum_Translator_vereinfacht.sch]
2020-10-11 simplified schematic with VOM1271
    [BMT BionX_Minimum_Translator_vereinfacht.kicad_pcb, BMT BionX_Minimum_Translator_vereinfacht.sch]
2020-10-12 PCB layout with SMD: first try
    [BMT BionX_Minimum_Translator_vereinfacht.sch]
2020-10-12 switched to 0805 Size
    [BMT BionX_Minimum_Translator_vereinfacht.kicad_pcb, BMT BionX_Minimum_Translator_vereinfacht.sch]
2020-10-12 schematic as pdf updated
    [BMT BionX_Minimum_Translator_vereinfacht.sch]
2020-10-12 2 Layer routing
    [BMT BionX_Minimum_Translator_vereinfacht.kicad_pcb, BMT BionX_Minimum_Translator_vereinfacht.sch]
2020-10-12 schematic as PDF
2020-10-12 Step Down switched seperately
    [BMT BionX_Minimum_Translator_vereinfacht.kicad_pcb, BMT BionX_Minimum_Translator_vereinfacht.sch]
2020-10-14 separated voltage regulators as alternative added.
    [BMT BionX_Minimum_Translator_vereinfacht.kicad_pcb]
2020-11-07 added filter for speedsignal
    [BMT BionX_Minimum_Translator_vereinfacht.sch]

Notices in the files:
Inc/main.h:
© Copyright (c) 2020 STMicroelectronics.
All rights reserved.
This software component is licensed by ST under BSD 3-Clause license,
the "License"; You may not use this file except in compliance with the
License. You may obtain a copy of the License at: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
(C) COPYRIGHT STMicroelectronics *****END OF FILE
